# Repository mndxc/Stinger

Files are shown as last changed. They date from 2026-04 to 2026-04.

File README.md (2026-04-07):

# Stinger — USB Audio Soundboard
<p align="center">
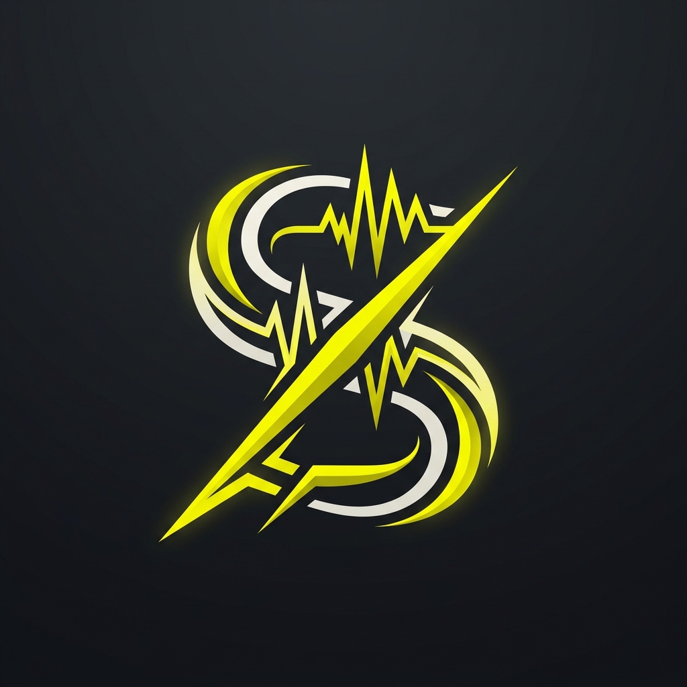
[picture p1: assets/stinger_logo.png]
Stinger Logo
  
</p>

<p align="center">
  <strong>High-performance, ultra-low latency audio workstation powered by ESP32-S3.</strong>
</p>

<p align="center">
  
  
  
  
</p>

---

**Stinger** is a professional-grade USB Audio Soundboard and interface designed for creators, streamers, and audio enthusiasts. Built on the **ESP32-S3** and the **ES8388 Audio Codec**, it combines a high-fidelity sound engine with a modular, tactile hardware interface.

## ✨ Key Features

- **🚀 Professional Audio Engine**: 16-bit / 48kHz PCM playback with sub-10ms trigger latency.
- **🎹 5×5 Matrix Input**: 25 tactile keys with integrated **1N4148 ghosting protection** for complex multi-key triggers.
- **📟 Sharp UI**: 2.9" E-Paper display (296x128) providing high-contrast bank indicators, labels, and real-time status.
- **🔊 Dual Rotary Encoders**: Dedicated physical controls for **System Bank Switching** and **SD Gain Leveling**.
- **💾 PSRAM Powered**: High-speed pre-loading of audio samples (up to 30s) into 8MB PSRAM for instantaneous playback.
- **🏗️ Modular Architecture**: Unique "Hinge" design with a specialized **Brain PCB** (SMT) and a hand-soldered **Plate PCB** (UI).
- **🔄 Auto-Sync Master Pin Map**: Smart build system that ensures hardware schematics and firmware constants are always in sync.

---

## 🏗️ Hardware Architecture: The "Long-Strap" Console

Stinger utilizes a modular **Two-Board Hinge** design to optimize signal integrity and mechanical stability.

- **Brain PCB (Base):** Optimized for signal integrity. Houses the ESP32-S3, high-fidelity ES8388 Codec, MicroSD slot, and power management.
- **Plate PCB (Interface):** Designed for manual assembly. Houses the 25-button MX-style matrix and the E-paper display.
- **Interconnect:** High-density 14-pin IDC ribbon headers connect the two layers, providing a robust electronic and mechanical bond.

> [!IMPORTANT]
> For full technical requirements, BOM, and assembly guides, see the [Hardware Specification](hardware/HARDWARE_SPEC.md).

---

## ⚙️ Firmware Stack: 3-Layer Architectural Model

Built on **ESP-IDF v6.0**, the firmware follows a strict 3-layer model to ensure long-term maintainability and performance:

1.  **Layer 1 (Drivers):** Low-level I2C/I2S/SPI drivers for the ES8388, E-Paper, and Matrix.
2.  **Layer 2 (Middleware):** High-level services for Audio Mixing (3-stream), SD management (with mutex protection), and USB UAC1/MSC stacks.
3.  **Layer 3 (Application):** The "Brain" of Stinger, coordinating state transitions, bank switching, and user event mapping.

> [!TIP]
> Check out the [Firmware Specification](firmware/stinger/FIRMWARE_SPEC.md) for task maps and concurrency details.

---

## 🚀 Getting Started

Ready to build your own Stinger? Follow these steps:

1.  **Clone the Repository:** `git clone https://github.com/mndxc/Stinger.git`
2.  **Environment Setup:** Follow the [GETTING_STARTED.md](GETTING_STARTED.md) guide.
3.  **Build & Flash:** 
    ```bash
    idf.py set-target esp32s3
    idf.py build
    idf.py flash monitor
    ```

---

## 📂 Repository Layout

```text
Stinger/
├── SPEC.md            # Master Project Overview & Master Pin Contract
├── hardware/          # KiCad design files, BOM, & Fabrications
├── firmware/          # ESP-IDF v6.0 source code & build tools
│   └── stinger/       # Main application logic
├── tools/             # Python utilities for pin-gen and audio prep
├── assets/            # Bitmap fonts, icons, and sample packs
└── build/             # Compiled artifacts (Git ignored)
```

---

## 📜 License

Distributed under the GNU General Public License v3.0. See `LICENSE` for more information.

**Project Lead:** [JP+](https://github.com/jonathanpool) | **Version:** 1.9 (Architectural Alignment)

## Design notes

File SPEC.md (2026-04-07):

# Stinger
## USB Audio Soundboard — Overview & Master Specification
**Revision 1.8 (Architectural Alignment) – Split Edition**
**Project:** Stinger | **Manufacturer:** JP+

> This document serves as the top-level project overview and the **Master Contract** between the Hardware and Firmware domains. For detailed subsystem specifications, refer to the linked documents below.

---

## 1. Project Specifications

The specification has been cleanly divided into hardware and firmware domains for ease of development:

- **[Hardware Specification](hardware/HARDWARE_SPEC.md)**: Schematics, layout guidelines, BOM, and protection circuitry.
- **[Firmware Specification](firmware/stinger/FIRMWARE_SPEC.md)**: RTOS tasks, display layouts, sound engine concurrency, and architecture guidelines.

---

## 2. Architecture: The "Long-Strap" Console

The Stinger uses a modular Two-Board Hinge design to optimize signal integrity and mechanical stability.

- **Brain PCB (Base):** Houses the ESP32-S3, ES8388 Codec, MicroSD slot, Power Section, and Rear I/O. Uses **Professional SMT** for fine-pitch ICs and **Manual THT** for IDC interconnects.
- **Plate PCB (Interface):** Houses the 25-button matrix and the 2.9" E-paper display. Fully **Hand-Soldered**.
- **Interconnect:** Two standard 14-pin IDC ribbon cables (2.54mm pitch) connect the boards via THT shrouded headers.

---

## 3. Master Pin Mapping & Matrix (The Contract)

**Note on Single Source of Truth:** This section is the *absolute contract* between the hardware design and the firmware implementation. Neither domain dictates the pins independently. 
- **Hardware:** Routes the schematics matching this table.
- **Firmware:** Reads from this table to define `firmware/main/pin_map.h`, which is the *code's* source of truth.

### 3.1 Pin Alignment Automation
To prevent "split-brain" discrepancies between PCB schematics and firmware constants, this project employs a centralized code generation strategy.
- **Source of Truth:** The pins are exclusively defined in `firmware/stinger/master_pins.json`.
- **Developer Workflow:** Setting your IDE workspace to `firmware/stinger/` is fully supported and recommended. You edit the JSON file directly. 
- **Under the Hood:** During CMake generation (`idf.py build` or `ninja`), a Python script (`tools/generate_pins.py`) is automatically executed. It builds `pin_map.h` for the firmware compiler and dynamically updates the Markdown table below. The script resolves paths natively relative to itself, meaning you can trigger builds and code-generation from any valid workspace context or terminal folder without filepath errors.

### 3.2 Pin Assignment Table (Rev V37)

<!-- PINS_START -->
<!-- The table below is auto-generated from firmware/stinger/master_pins.yaml during build. Do not edit. -->
| Pin Name | GPIO | Description/Note |
|---|---|---|
| `PIN_USB_D_MINUS` | GPIO 19 | USB D- |
| `PIN_USB_D_PLUS` | GPIO 20 | USB D+ |
| `PIN_I2S_BCLK` | GPIO 38 | I2S BCLK (Audio Data) |
| `PIN_I2S_LRCK` | GPIO 39 | I2S LRCK (Audio Data) |
| `PIN_I2S_DOUT` | GPIO 40 | I2S DOUT (Audio Data) |
| `PIN_I2S_DIN` | GPIO 41 | I2S DIN (Audio Data) |
| `PIN_I2S_MCLK` | GPIO 0 | I2S MCLK (CLK_OUT1. 256xFs = 12.288 MHz) |
| `PIN_I2C_SDA` | GPIO 4 | I2C SDA (Control) |
| `PIN_I2C_SCL` | GPIO 5 | I2C SCL (Control) |
| `PIN_SPI2_CS` | GPIO 10 | SPI2 CS (MicroSD) |
| `PIN_SPI2_MOSI` | GPIO 11 | SPI2 MOSI (MicroSD) |
| `PIN_SPI2_SCK` | GPIO 12 | SPI2 SCK (MicroSD) |
| `PIN_SPI2_MISO` | GPIO 13 | SPI2 MISO (MicroSD) |
| `PIN_SPI3_CS` | GPIO 21 | SPI3 CS (E-Paper) on non-strapping pin |
| `PIN_SPI3_DIN` | GPIO 16 | SPI3 DIN (E-Paper) |
| `PIN_SPI3_CLK` | GPIO 17 | SPI3 CLK (E-Paper) |
| `PIN_SPI3_DC` | GPIO 18 | SPI3 DC (E-Paper) |
| `PIN_SPI3_RST` | GPIO 7 | SPI3 RST (E-Paper) |
| `PIN_SPI3_BUSY` | GPIO 6 | SPI3 BUSY (E-Paper) |
| `PIN_MATRIX_ROW_0` | GPIO 1 | Matrix Row 0 |
| `PIN_MATRIX_ROW_1` | GPIO 2 | Matrix Row 1 |
| `PIN_MATRIX_ROW_2` | GPIO 42 | Matrix Row 2 |
| `PIN_MATRIX_ROW_3` | GPIO 43 | Matrix Row 3 |
| `PIN_MATRIX_ROW_4` | GPIO 25 | Matrix Row 4 |
| `PIN_MATRIX_COL_0` | GPIO 8 | Matrix Col 0 |
| `PIN_MATRIX_COL_1` | GPIO 15 | Matrix Col 1 (moved from GPIO 3 strapping pin) |
| `PIN_MATRIX_COL_2` | GPIO 44 | Matrix Col 2 |
| `PIN_MATRIX_COL_3` | GPIO 9 | Matrix Col 3 |
| `PIN_MATRIX_COL_4` | GPIO 24 | Matrix Col 4 |
| `PIN_ENC1_A` | GPIO 47 | Encoder 1 A (Bank switching) |
| `PIN_ENC1_B` | GPIO 14 | Encoder 1 B (Bank switching) |
| `PIN_ENC2_A` | GPIO 22 | Encoder 2 A (SD Gain) |
| `PIN_ENC2_B` | GPIO 23 | Encoder 2 B (SD Gain) |
| `PIN_SD_DETECT` | GPIO 26 | SD Card Detect (Active low) |
| `PIN_STATUS_LED` | GPIO 48 | Status RGB LED |
<!-- PINS_END -->

### 3.2 Logical Matrix Map (5×5)

| Row \ Col | Col 0 (GPIO 8) | Col 1 (GPIO 15) | Col 2 (GPIO 44) | Col 3 (GPIO 9) | Col 4 (GPIO 24) |
|---|---|---|---|---|---|
| Row 0 (GPIO 1)  | Trigger L1 | Trigger L2 | Trigger L3 | Trigger L4 | Reserved |
| Row 1 (GPIO 2)  | Trigger R1 | Trigger R2 | Trigger R3 | Trigger R4 | Reserved |
| Row 2 (GPIO 42) | Fav 1 | Fav 2 | Fav 3 | Fav 4 | Reserved |
| Row 3 (GPIO 43) | Fav 5 | Shift Key | Enc 1 Switch | Enc 2 Switch | Reserved |
| Row 4 (GPIO 25) | Reserved | Reserved | Reserved | Reserved | Reserved |

---

## 4. Repository Layout

```
stinger/
│
├── SPEC.md                        # This document (Project Overview & Master Pin Contract)
├── hardware/
│   ├── HARDWARE_SPEC.md           # Master hardware requirements
│   ├── brain/ ...
│   ├── plate/ ...
│   └── fabrication/ ...
│
├── firmware/
│   ├── stinger/
│   │   ├── master_pins.json       # Source of Truth for Pins
│   │   ├── FIRMWARE_SPEC.md       # Master firmware requirements
│   │   ├── main/
│   │   │   ├── pin_map.h          # Auto-generated code implementation
│   │   │   ├── board_config.h
│   │   │   └── stinger_app.c
│   │   ├── components/ ...
│   │   └── tools/
│   │       └── generate_pins.py   # Generator script
└── assets/ ...
```

---

## Revision History

| Revision | Summary of Changes |
|---|---|
| 1.0 | Initial consolidated release. |
| 1.1 | GPIO 15 → 21 for SPI3 CS. Matrix map added. FreeRTOS task map added. |
| 1.2 | Encoder phases moved off matrix to dedicated interrupt GPIOs. Priority order corrected. PSRAM loading strategy defined. SD mutex and Transfer Mode state machine specified. |
| 1.3 | GPIO 15 → 22 and GPIO 46 → 23 for Encoder 2 A/B (strapping-pin conflicts). Maximum sample length added. Transfer Mode VBUS exit clarified. Citation artifact removed. |
| 1.4 | Sample format changed to mono. Mixer routing clarified. Sample completion behavior defined. Max sample length extended to 30s. Variable PSRAM allocation. |
| 1.5 | Codec replaced: WM8960 (EOL) → ES8388 (C365736). MCLK added to pin map. Encoder 1 assigned to bank switching. Display specification added. Label file format defined. 99-bank system defined. Project directory added. ESP-IDF v5.3 target defined. |
| 1.6 | Full protection circuitry restored. SD card-detect added (GPIO 26). BOM rationalised. |
| 1.7 | Project renamed to **Stinger** by JP+. USB descriptor strings defined. Boot splash screen specified. |
| 1.8 | Formalized 3-Layer Architectural model. Document split into Hardware/Firmware specs, leaving Master Pin Contract in root `SPEC.md`. |
| 1.9 | Updated framework requirement to ESP-IDF v6.0 to align with current IDE extension defaults. |

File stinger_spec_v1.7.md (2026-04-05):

# Stinger
## USB Audio Soundboard — Comprehensive Design & Manufacturing Specification
**Revision 1.7 (V37 Consolidated)**
**Project:** Stinger | **Manufacturer:** JP+

> This document serves as the production-ready specification and design guide for the Stinger USB Audio Soundboard by JP+. This revision applies the project name throughout, defines USB device descriptor strings, and adds the boot splash screen specification.

---

# PART I: MASTER SYSTEM SPECIFICATION

---

## 1. Architecture: The "Long-Strap" Console

The Stinger uses a modular Two-Board Hinge design to optimize signal integrity and mechanical stability.

- **Brain PCB (Base):** Houses the ESP32-S3, ES8388 Codec, MicroSD slot, Power Section, and Rear I/O.
- **Plate PCB (Interface):** Houses the 16-button matrix and the 2.9" E-paper display.
- **Interconnect:** Two standard 10-pin IDC ribbon cables (2.54mm pitch) connect the boards.

---

## 2. Hardware Specification

### 2.1 MCU Module

- **Model:** ESP32-S3-WROOM-1-N8R8 (Octal SPI).
- **Forbidden Pins:** GPIO 33–37 (internal PSRAM/Flash).
- **Strapping:** GPIO 0 HIGH (10kΩ); GPIO 45 (VDD_SPI) LOW for 3.3V flash operation.

### 2.2 Audio Subsystem

- **Codec:** ES8388 (QFN-28, 4×4mm) by Everest Semiconductor. Actively manufactured.
- **Configuration:** 48kHz / 16-bit PCM, I2S slave mode.
- **I2C Address:** 0x10 (CE pin LOW) or 0x11 (CE pin HIGH). CE pin state must be defined in schematic and matched in `board_config.h`.
- **Output:** Board-mount 3.5mm TRRS jack (CTIA) on the front panel.
- **Power Pins:**

| ES8388 Supply Pin | Connected Rail | Notes |
|---|---|---|
| DVDD | 3.3V_D | Digital core supply. |
| AVDD | 3.3V_A | ADC/DAC analog supply. Isolated via ferrite bead + 10µF cap. |
| PVDD | 3.3V_D | PLL supply. Shares with DVDD. |
| HPVDD | 3.3V_D | Headphone amp supply. Decouple with 10µF + 100nF locally. |

### 2.3 TRRS Signal Path

| TRRS Pin (CTIA) | Signal | ES8388 Connection |
|---|---|---|
| Tip | Left Audio Out | LOUT1 via 1µF DC blocking cap, then PRTR5V0U2X TVS to GND |
| Ring 1 | Right Audio Out | ROUT1 via 1µF DC blocking cap, then PRTR5V0U2X TVS to GND |
| Ring 2 | Microphone In | LIN1 via 2.2kΩ bias resistor from MICBIAS, then PRTR5V0U2X TVS to GND |
| Sleeve | Ground | AGND |

> **TVS placement:** PRTR5V0U2X devices placed between TRRS jack pins and DC blocking caps / bias resistors. One package covers two channels — use two packages for all three active lines. Fourth channel is spare.

---

## 3. Protection & Glue Circuitry

### 3.1 USB Protection

- **VBUS PTC Fuse:** MF-MSMF050-2 (500mA hold, 1A trip, 1812) in series with VBUS before any other circuitry.
- **USB ESD:** USBLC6-2SC6 (SOT-23-6) placed immediately after USB-C connector pins, before PTC fuse. Rated 8kV contact discharge per IEC 61000-4-2.

### 3.2 TRRS Protection

- **TVS:** PRTR5V0U2X,215 (SOT-143, dual-channel). Two packages. Placed between jack pins and signal conditioning.

### 3.3 Matrix & Encoder Protection

- **Series Resistors:** 100Ω (0402) on every matrix Row and Column GPIO line (8 lines total).
- **Encoder Phase Lines:** 100Ω series resistors on all four encoder phase GPIOs (47, 14, 22, 23).

### 3.4 Programming & Reset Logic

- **Auto-Reset Circuit:** Dual NPN transistors (S8050) on RTS/DTR for automatic bootloader entry.
- **EN (Reset) Pin:** 10kΩ pull-up to 3.3V + 100nF cap to GND.
- **Boot Pin (GPIO 0):** 10kΩ pull-up to 3.3V + tactile button for manual Download Mode.
- **EN Button:** Tactile button for manual hardware reset.

### 3.5 Power & Status

- **Power Indicator:** Red LED on 3.3V rail via 1kΩ resistor.
- **Activity Indicator:** RGB LED on GPIO 48.
- **Ferrite Bead:** BLM18 series 0402 between 3.3V_D and 3.3V_A. 10µF + 100nF decoupling on 3.3V_A.

### 3.6 SD Card Detect

- MicroSD slot card-detect switch pin wired to GPIO 26.
- Firmware monitors via interrupt. Falling edge (removal) triggers clean unmount. Rising edge (insertion) triggers re-mount and Bank 01 reload.

---

## 4. Master Pin Mapping & Matrix

### 4.1 Pin Assignment Table (Rev V37)

| Bus / Function | Pin Assignment | Note |
|---|---|---|
| USB D− / D+ | GPIO 19 / 20 | |
| I2S (Audio Data)  | BCLK: 38, LRCK: 39, DOUT: 40, DIN: 41 | |
| I2S MCLK | GPIO 0 | CLK_OUT1. 256×Fs = 12.288 MHz. Enable after codec I2C init.  |
| I2C (Control) | SDA: 4, SCL: 5 | |
| SPI2 (MicroSD) | CS: 10, MOSI: 11, SCK: 12, MISO: 13 | |
| SPI3 (E-Paper) | CS: 21, DIN: 16, CLK: 17, DC: 18, RST: 7, BUSY: 6  | CS on non-strapping pin. |
| Matrix Rows | GPIO 1, 2, 42, 43 | Rows 0–3. 100Ω series on all row lines. |
| Matrix Cols | GPIO 8, 3, 44, 9 | Cols 0–3. 100Ω series on all col lines. |
| Encoder 1 A/B | GPIO 47, 14 | Dedicated interrupts. Bank switching. 100Ω series. |
| Encoder 2 A/B | GPIO 22, 23 | Dedicated interrupts. SD Gain. 100Ω series. |
| SD Card Detect | GPIO 26 | Active low. Card-detect switch on MicroSD slot. |
| Status RGB LED | GPIO 48 | |

### 4.2 Logical Matrix Map (4×4)

| Row \ Col | Col 0 (GPIO 8) | Col 1 (GPIO 3) | Col 2 (GPIO 44) | Col 3 (GPIO 9) |
|---|---|---|---|---|
| Row 0 (GPIO 1)  | Trigger L1 | Trigger L2 | Trigger L3 | Trigger L4 |
| Row 1 (GPIO 2)  | Trigger R1 | Trigger R2 | Trigger R3 | Trigger R4 |
| Row 2 (GPIO 42) | Fav 1 | Fav 2 | Fav 3 | Fav 4 |
| Row 3 (GPIO 43) | Fav 5 | Shift Key | Enc 1 Switch | Enc 2 Switch |

---

## 5. Display Specification

### 5.1 Hardware

- **Module:** Waveshare 2.9" E-paper, 296×128 pixels, portrait orientation (296px tall, 128px wide).
- **Interface:** SPI3 (dedicated bus).

### 5.2 Boot Splash Screen

On power-up, before Bank 01 is loaded, the Stinger displays a full-screen splash for 2 seconds:

```
┌────────────────────────────────┐
│                                │
│                                │
│                                │
│           STINGER              │  ← Large bold centered text (~48px tall)
│                                │
│             JP+                │  ← Smaller centered text (~20px tall)
│                                │
│                                │
│                                │
└────────────────────────────────┘
```

- **STINGER:** Large bold font, centered horizontally and vertically in the upper two-thirds of the display.
- **JP+:** Smaller font, centered beneath, with adequate spacing from STINGER.
- The splash uses the same full E-paper init refresh that occurs at power-on, so no additional refresh cycle is incurred.
- After 2 seconds, transition to the main Bank view (Zone layout, Section 5.3).
- If SD card is absent at boot, splash displays normally, then transitions to `NO SD CARD` state.

### 5.3 Main Screen Layout

```
┌────────────────────────────────┐  ← 0px
│         BANK INDICATOR         │  Zone 1: ~24px
├────────────────────────────────┤  ← 24px
│ ◄ L1  [     label text     ]   │
│ ◄ L2  [     label text     ]   │  Zone 2: 8 rows
│ ◄ L3  [     label text     ]   │  ~26px each = ~208px
│ ◄ L4  [     label text     ]   │
│    [ label text     ]  R1 ►    │
│    [ label text     ]  R2 ►    │
│    [ label text     ]  R3 ►    │
│    [ label text     ]  R4 ►    │
├────────────────────────────────┤  ← 232px
│  VOL: ██████░░  GAIN: ████░░░  │  Zone 3: ~32px
│  USB ●  SD ●  XFER ○           │
└────────────────────────────────┘  ← 296px
        ←── 128px wide ───→
```

**Zone 1 — Bank Indicator (~24px):**
- Centered bold: `Bank 03 / 99`
- Thin horizontal rule below.

**Zone 2 — Button Label Rows (~208px, ~26px per row):**
- Rows 1–4: Left buttons (L1–L4). `◄` at left edge, label left-aligned.
- Rows 5–8: Right buttons (R1–R4). Label right-aligned, `►` at right edge.
- Labels from `labels.cfg` if present, otherwise WAV filename without extension.
- Long labels truncated with ellipsis to fit 110px.
- Missing WAV slot displays `---`, key silenced.

**Zone 3 — Status Bar (~32px):**
- Row 1: Bar indicators for System Volume and SD Gain.
- Row 2: USB `●`, SD `●`, Transfer Mode `●` indicators.
- Lowest rendering priority — omitted cleanly if layout requires.

### 5.4 Bank Switching

- **Control:** Encoder 1. CW = next bank, CCW = previous bank. Wraps at boundaries.
- **At bank switch:** Full E-paper refresh. Active playback not interrupted.
- **Boot default:** Bank 01. Displays `NO BANK LOADED` if `/bank01/` absent.
- **On SD removal:** Displays `NO SD CARD`.
- **On SD insertion:** Reloads Bank 01 and refreshes display.

### 5.5 Label Files

```
# /bank01/labels.cfg
L1=Airhorn
L2=Rimshot
L3=Applause
L4=Sad Trombone
R1=Cash Register
R2=Crickets
R3=Wilhelm
R4=Ba Dum Tss
```

---

## 6. Firmware & Concurrency

### 6.1 Development Environment

- **Framework:** ESP-IDF v5.3 standalone.
- **ES8388 Driver:** Adapted from ESP-ADF `components/audio_hal/driver/es8388/`. Local component — no ESP-ADF pipeline dependency.
- **USB Stack:** TinyUSB (bundled with ESP-IDF v5.x). Composite device via `tusb_config.h`.
- **Target:** `esp32s3`. Dual-core task pinning via `xTaskCreatePinnedToCore`.

### 6.2 USB Device Descriptor Strings

| Descriptor Field | Value | Notes |
|---|---|---|
| Manufacturer | `JP+` | Appears in host OS device manager. |
| Product | `Stinger` | Appears as audio device and MSC drive name. |
| Serial Number | TBD | Can use ESP32-S3 unique MAC-derived ID at runtime. |
| UAC1 Interface | `Stinger Audio` | Audio device name shown in host audio settings. |
| MSC Volume Label | `STINGER` | Drive label shown in host file manager during Transfer Mode. |

### 6.3 FreeRTOS Task Map

| Core | Task Name | Priority | Responsibility |
|---|---|---|---|
| Core 1 | AudioMixerTask | 25 (Max) | SD data fetch, 3-stream mixing, I2S DMA. |
| Core 0 | UsbStackTask | 22 | UAC1, HID, and MSC events. |
| Core 0 | InputScanTask  | 20 | 4×4 matrix scan (1ms). Encoder rotation via interrupts. |
| Core 1 | SdManagerTask  | 15 | File handles, MSC data piping, card-detect handler. |
| Core 0 | DisplayTask | 2 | E-paper SPI refreshes. |

### 6.4 Playback Logic

- **Mode:** Retrigger — new key press restarts sample from beginning.
- **Sample Format:** 16-bit PCM, 48kHz Mono WAV.
- **Routing:** Samples sum into mono mic capture path → UAC1 capture stream to host.
- **Stream Summary:**
  - **UAC1 Capture (to PC):** Mono mic + mono SD sample (summed).
  - **UAC1 Playback (from PC):** Stereo USB audio → headphone output.
  - **Headphone Output:** Stereo USB playback + sidetone.
- **Sample Completion:** Sample channel zeroed on buffer exhaustion. Clean return to mic-only.

### 6.5 Encoder Logic

| Encoder | Function | Notes |
|---|---|---|
| Encoder 1 | Bank Switching | CW = next bank, CCW = previous bank. Wraps. |
| Encoder 2 | SD Gain | Internal mixer scaling. No HID event emitted. |

### 6.6 Sample File Specification

- **Format:** 16-bit PCM, 48kHz Mono WAV.
- **Typical Length:** Under 6 seconds (~576 KB).
- **Maximum Length:** 30 seconds hard cap (~2.88 MB). Boot loader rejects oversized files, logs via USB CDC.
- **Loading Strategy:** Pre-loaded into PSRAM at boot or bank-switch. Per-file allocation.
- **Naming:** `/bankXX/YY.wav` — XX = zero-padded bank (01–99), YY = button index (01–08).
- **Button index mapping:** 01–04 = L1–L4, 05–08 = R1–R4.

> **PSRAM budget:** 8 × 2.88 MB theoretical max ≈ 23 MB. Hard cap enforced at load time. Typical usage well under 5 MB.

### 6.7 Concurrency & Transfer Mode

#### SD Mutex Strategy
All SD access gated by `sd_card_mutex`. No task reads or writes SD without holding this mutex.

#### SD Card-Detect Handler
On removal (GPIO 26 falling edge): `AudioMixerTask` drains and suspends, mutex released, filesystem unmounted. Display shows `NO SD CARD`. On insertion: filesystem re-mounted, Bank 01 loaded, `AudioMixerTask` resumed.

#### Transfer Mode State Machine
- **Entry:** 2-second Shift + Enc2 Switch hold. `AudioMixerTask` drains DMA buffer, suspends via `vTaskSuspend()`. Mutex released, filesystem unmounted, SD handed to USB MSC. Display shows `TRANSFER MODE`. MSC drive appears as `STINGER` on host.
- **Exit — Combo:** Same Shift + Enc2 Switch hold. Filesystem re-mounted, `AudioMixerTask` resumed.
- **Exit — USB Disconnect:** VBUS loss triggers same re-mount and resume. Do not rely on host enumeration signals.

#### Known Limitation — FAT32 Power Loss
FAT32 is not journaled. Power loss during Transfer Mode SD writes may cause filesystem corruption. Acceptable for prototype. Production mitigation: ESP-IDF FatFS wear-leveling layer.

---

# PART II: KICAD HARDWARE DESIGN

---

## 7. Board Layout Strategy

- **Zone A (Rear):** USB-C connector, USBLC6-2SC6, PTC fuse, Power Switch, LDO.
- **Zone B (Center):** ESP32-S3, IDC headers for ribbon cables.
- **Zone C (Front):** ES8388 Codec, TRRS jack, PRTR5V0U2X TVS devices.

> **ESD placement rule:** USBLC6-2SC6 within 5mm of USB-C pins, before PTC fuse. PRTR5V0U2X between TRRS jack pads and first passive on each signal line.

## 8. Signal Integrity & Safety

- **Analog Ground Island:** ES8388 AVDD and AGND on isolated copper island. Star-ground via 0Ω resistor near LDO.
- **Encoder Interrupts:** Dedicated GPIOs with 100Ω series resistors. Not matrix-scanned.
- **Ribbon Isolation:** SHIFT_KEY (Header B, Pin 9) kept distant from SPI_CLK (Header B, Pin 4).
- **Boot Window:** GPIO 1 and GPIO 3 tri-stated during power-on strapping window.
- **MCLK Boot Safety:** GPIO 0 MCLK output enabled only after ES8388 I2C init completes.
- **Debug:** All logs via USB CDC. UART0 unavailable in production.

---

## 9. Bill of Materials (Consolidated)

### 9.1 Primary ICs

| Component | Part | LCSC | Notes |
|---|---|---|---|
| MCU Module | ESP32-S3-WROOM-1-N8R8 | C2913148 | |
| Audio Codec | ES8388 | C365736 | QFN-28, 4×4mm |
| LDO Regulator | SGM2019-3.3 | C16193 | 3.3V, 300mA |

### 9.2 Protection

| Component | Part | LCSC | Notes |
|---|---|---|---|
| USB ESD | USBLC6-2SC6 | C7519 | SOT-23-6. ST. Within 5mm of USB-C pins. |
| TRRS TVS | PRTR5V0U2X,215 | C12333 | SOT-143, dual-channel. Nexperia. Qty: 2. |
| VBUS PTC Fuse | MF-MSMF050-2 | C17313 | 500mA hold / 1A trip. 1812. |

### 9.3 Passives (Consolidated)

| Value | Package | Role |
|---|---|---|
| 100nF | 0402 | Bypass / decoupling on all IC supply pins. |
| 1µF | 0402 | DC blocking on TRRS audio lines. |
| 10µF | 0805 | Bulk decoupling: 3.3V_A, HPVDD, LDO output. |
| 100Ω | 0402 | Series ESD protection: matrix rows, cols, encoder phases. |
| 1kΩ | 0402 | Power LED current limit. |
| 2.2kΩ | 0402 | MICBIAS to TRRS Ring 2. |
| 4.7kΩ | 0402 | I2C SDA/SCL pull-ups. |
| 10kΩ | 0402 | GPIO pull-ups: EN, Boot, strapping. |

### 9.4 Miscellaneous

| Component | Notes |
|---|---|
| USB-C Connector | Mid-mount or right-angle top-mount (e.g. LCSC C165948). |
| MicroSD Slot | Must include card-detect switch pin. Wire CD to GPIO 26. |
| TRRS Jack | PJ-320A or equivalent. 3.5mm board-mount. CTIA. |
| Tactile Buttons ×2 | EN reset + Boot mode. Standard 6×6mm. |
| Ferrite Bead | BLM18 series 0402. 3.3V_D → 3.3V_A isolation. |
| NPN Transistors ×2 | S8050. Auto-reset RTS/DTR circuit. |
| Red LED | Power indicator on 3.3V rail. |
| RGB LED | Activity/status on GPIO 48. |

---

# PART III: PROJECT STRUCTURE

---

## 10. Repository Layout

```
stinger/
│
├── SPEC.md                        # This document (canonical project reference)
├── README.md                      # Project overview and build instructions
├── .gitignore
│
├── hardware/
│   ├── brain/
│   │   ├── brain.kicad_pro
│   │   ├── brain.kicad_sch
│   │   ├── brain.kicad_pcb
│   │   └── brain_bom.csv
│   ├── plate/
│   │   ├── plate.kicad_pro
│   │   ├── plate.kicad_sch
│   │   └── plate.kicad_pcb
│   ├── symbols/
│   │   └── ES8388.kicad_sym
│   ├── footprints/
│   │   └── ES8388_QFN28.kicad_mod
│   └── fabrication/
│       ├── brain/
│       └── plate/
│
├── firmware/
│   ├── CMakeLists.txt
│   ├── sdkconfig
│   ├── sdkconfig.defaults
│   │
│   ├── main/
│   │   ├── CMakeLists.txt
│   │   ├── main.c
│   │   ├── pin_map.h              # Single source of truth for all GPIO assignments
│   │   └── board_config.h         # Constants: sample rate, bank count, I2C address, etc.
│   │
│   └── components/
│       ├── es8388/                # ES8388 driver (adapted from ESP-ADF, no ADF dependency)
│       │   ├── CMakeLists.txt
│       │   ├── es8388.c
│       │   └── es8388.h
│       ├── audio_mixer/
│       │   ├── CMakeLists.txt
│       │   ├── audio_mixer.c
│       │   └── audio_mixer.h
│       ├── usb_audio/             # TinyUSB composite: UAC1 + HID + MSC
│       │   ├── CMakeLists.txt
│       │   ├── usb_descriptors.c  # Descriptor tables. Strings: "JP+", "Stinger".
│       │   ├── usb_audio.c
│       │   └── usb_audio.h
│       ├── sd_manager/            # SD mount, file loading, card-detect, mutex
│       │   ├── CMakeLists.txt
│       │   ├── sd_manager.c
│       │   └── sd_manager.h
│       ├── input_handler/         # Matrix scan, encoder ISRs, bank switching
│       │   ├── CMakeLists.txt
│       │   ├── input_handler.c
│       │   └── input_handler.h
│       └── display/               # E-paper driver + zone renderer + boot splash
│           ├── CMakeLists.txt
│           ├── display.c          # SPI driver, Waveshare 2.9" init, splash sequence
│           ├── display.h
│           ├── layout.c           # Zone rendering: splash, bank view, error states
│           └── layout.h
│
├── tools/
│   ├── flash.sh                   # Wrapper for idf.py flash monitor
│   └── wav_prep.py                # Validates WAV files to spec before SD copy
│
└── assets/
    ├── fonts/                     # Bitmap fonts for E-paper rendering
    └── sample_banks/
        └── bank01/
            ├── 01.wav
            └── labels.cfg
```

### 10.1 Key File Conventions

- **`pin_map.h`** — single source of truth for all GPIO numbers. No magic numbers elsewhere.
- **`board_config.h`** — all non-GPIO constants: sample rate (48000), bit depth (16), max banks (99), max sample frames, ES8388 I2C address, MCLK frequency (12288000), USB strings (`"JP+"`, `"Stinger"`), splash duration (2000ms).
- **`sdkconfig`** — committed to repo. All developers and AI tools build against identical ESP-IDF config.
- **`wav_prep.py`** — validates WAV files for spec compliance (48kHz, 16-bit, mono) and checks duration against 30-second cap before SD copy.

---

## Revision History

| Revision | Summary of Changes |
|---|---|
| 1.0 | Initial consolidated release. |
| 1.1 | GPIO 15 → 21 for SPI3 CS. Matrix map added. FreeRTOS task map added. |
| 1.2 | Encoder phases moved off matrix to dedicated interrupt GPIOs. Priority order corrected. PSRAM loading strategy defined. SD mutex and Transfer Mode state machine specified. |
| 1.3 | GPIO 15 → 22 and GPIO 46 → 23 for Encoder 2 A/B (strapping-pin conflicts). Maximum sample length added. Transfer Mode VBUS exit clarified. Citation artifact removed. |
| 1.4 | Sample format changed to mono. Mixer routing clarified. Sample completion behavior defined. Max sample length extended to 30s. Variable PSRAM allocation. |
| 1.5 | Codec replaced: WM8960 (EOL) → ES8388 (C365736). MCLK added to pin map. Encoder 1 assigned to bank switching. Display specification added. Label file format defined. 99-bank system defined. Project directory added. ESP-IDF v5.3 target defined. |
| 1.6 | Full protection circuitry restored: VBUS PTC fuse (C17313), USB ESD (C7519), TRRS TVS (C12333 ×2), matrix 100Ω series resistors. SD card-detect added (GPIO 26). BOM rationalised to 8 passive values. FAT32 power-loss limitation documented. |
| 1.7 | Project renamed to **Stinger** by JP+. Name applied throughout all sections and directory structure. USB descriptor strings defined: Manufacturer `JP+`, Product `Stinger`, UAC1 `Stinger Audio`, MSC volume `STINGER`. Serial number deferred to runtime MAC-derived ID. Boot splash screen specified (2s, STINGER / JP+ centered). USB strings added to `board_config.h` conventions. |

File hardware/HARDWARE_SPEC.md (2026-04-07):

# Stinger: Hardware Specification
**Revision 1.9 — Hybrid Assembly Model**

> [!IMPORTANT]
> **Navigation & Source of Truth**  
> *   **Pin Mapping:** Refer to the root [SPEC.md](file:///Users/jonathanpool/Projects/Stinger/SPEC.md) (Source of Truth).
> *   **Detailed Design Notes:** Refer to [KICAD_DESIGN_NOTES.md](file:///Users/jonathanpool/Projects/Stinger/hardware/KICAD_DESIGN_NOTES.md) for layout rules.
> *   **BOM & Sourcing:** The table in **Section 5** of *this document* is the absolute Source of Truth for parts.

---

## 1. Assembly Strategy

The Stinger uses a **Hybrid Assembly Model** to balance complexity and ease of construction:

| Board | Assembly Method | Description |
|---|---|---|
| **Brain PCB** | **Mixed Mode** | **Professional SMT** for fine-pitch ICs/passives. **Manual THT** for IDC headers. |
| **Plate PCB** | **Hand-Soldered** | Contains buttons, diodes, and through-hole headers. Uses larger pads (0805 or THT) for manual assembly. |

---

## 2. Hardware Specification

### 2.1 MCU Module
- **Model:** ESP32-S3-WROOM-1-N8R8.
- **Strapping:** GPIO 0 HIGH (10kΩ); GPIO 45 LOW (10kΩ).

### 2.2 Audio Subsystem
- **Codec:** ES8388 (QFN-28). 48kHz / 16-bit PCM.
- **I2C Address:** 0x10 (CE pin LOW).

### 2.3 TRRS signal Path
- **Protection:** PRTR5V0U2X TVS devices on all active lines. 1µF DC-blocking caps on L/R outputs.

### 2.4 Matrix & Input Protection
- **Series Resistors:** **100Ω (0402)** on all matrix lines and encoder phases. **Located on Brain PCB** for professional placement.
- **Ghosting Protection:** **25× 1N4148 diodes** (SOD-123 or THT). **Located on Plate PCB** at each switch node.
- **Orientation:** Cathode to Matrix Row (for active-low scan).

### 2.5 E-Paper Display Module
- **Model:** 2.9" E-Paper Module (e.g., Waveshare).
- **Interconnect:** **8-pin through-hole header (2.54mm)** on Plate PCB. Hand-wired to the display module.

### 2.6 SD Card & Power
- **SD Slot:** Includes card-detect switch on GPIO 26.
- **Auto-Reset:** Dual S8050 NPN circuit for RTS/DTR.

---

## 3. Board Layout Strategy

- **Brain (SMT Zone):** Concentrated fine-pitch routing for audio/USB. IDC headers are THT and should be soldered manually after SMT assembly to save on fixture fees.
- **Plate (Manual Zone):** Spacious layout for MX-style keys, 0805 resistors (if any), and easily accessible THT pads for the display module and IDC headers.

---

## 4. Maintenance & Change Management

To keep the hardware and software in sync, follow these rules for every change:
1.  **Pins:** Update `firmware/stinger/master_pins.json` first. Run `idf.py build` to propagate changes to `SPEC.md`.
2.  **BOM:** Update Section 5 of this document.
3.  **Footprints:** If switching from SMD to THT on the Plate, update the KiCad project and this spec simultaneously.

---

## 5. Bill of Materials (Master Source of Truth)

### 5.1 Brain PCB — Professional SMT Items (LCSC)

| Component | Part / Value | LCSC | Note |
|---|---|---|---|
| MCU | ESP32-S3-WROOM-1-N8R8 | C2913148 | |
| Audio Codec | ES8388 | C365736 | QFN-28 |
| LDO | SGM2019-3.3 | C16193 | 3.3V, 300mA |
| USB ESD | USBLC6-2SC6 | C7519 | Within 5mm of USB-C |
| TRRS TVS | PRTR5V0U2X,215 | C12333 | Qty: 2 |
| PTC Fuse | MF-MSMF050-2 | C17313 | 1812 package |
| USB-C | RA Top-Mount | C165948 | |
| MicroSD | With Card Detect | C91145 | |
| Series Resists | 100Ω (0402) | | Qty: 14 |
| Passives | 100nF, 1uF, 10uF | | Refer to KiCad Project |

### 5.2 Brain PCB — Hand-Soldered / User-Side Items
*These items are through-hole and should be installed manually to avoid JLCPCB's THT assembly and fixture surcharges.*

| Component | Part / Value | LCSC | Note |
|---|---|---|---|
| IDC Headers | 2×7 Box Header | C2922129 | 2.54mm THT. Placed on top side. |

### 5.3 Plate PCB — Hand-Soldered / Manual Items
*This entire board is intended for manual assembly.*

| Component | Part / Value | Sourcing | Note |
|---|---|---|---|
| Keys | MX-Style or Tactile | Generic | 25 required |
| Diodes | 1N4148W (SOD-123) | C1661 | or THT 1N4148 (C467) |
| IDC Headers | 2×7 Box Header | C2922129 | 2.54mm THT. Placed on bottom side. |
| E-Paper | 2.9" Module | Waveshare | With 8-pin breakout |
| Status LED | WS2812B (5050) | C114586 | 1 required |
| Ribbon Cable | 14-pin IDC Assembly | Generic | Qty: 2 |

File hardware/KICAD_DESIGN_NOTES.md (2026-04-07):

# Stinger — KiCad Design Notes
**Revision 2.0 — Hybrid Assembly Edition**

> [!IMPORTANT]
> **Navigation & Source of Truth**  
> *   **Pin Mapping:** Refer to the root [SPEC.md](file:///Users/jonathanpool/Projects/Stinger/SPEC.md) (Source of Truth).
> *   **Master BOM:** All part numbers and LCSC codes are in [HARDWARE_SPEC.md §5](file:///Users/jonathanpool/Projects/Stinger/hardware/HARDWARE_SPEC.md#L98).
> *   **Sync:** Update `master_pins.json` before changing any schematic nets.

---

## 1. Assembly & Sourcing Strategy

The Stinger is a **two-board design** optimized for a mix of professional and manual construction:

| Board | Directory | Assembly | Key Contents |
|---|---|---|---|
| **Brain PCB** | `hardware/brain/` | **Mixed Mode** | **Professional SMT** for fine-pitch ICs/passives. **Manual THT** for IDC headers. |
| **Plate PCB** | `hardware/plate/` | **Hand-Soldered** | Buttons, Ghosting Diodes, WS2812B, and IDC Headers. |

---

## 2. MCU Module — ESP32-S3-WROOM-1-N8R8

### 2.1 Strapping Pins — Critical at Power-On
These pins determine the boot mode. Ensure the Brain PCB includes these 10kΩ pull-up/down resistors for the SMT machine to place.

| GPIO | Required Level | Implementation |
|---|---|---|
| **GPIO 0** (Boot) | HIGH | 10kΩ pull-up. Tactile button to GND for Download Mode. |
| **GPIO 45** (VDD_SPI) | LOW | 10kΩ pull-down. Selects 3.3V internal flash. |

### 2.2 MCLK Boot Safety (GPIO 0)
- GPIO 0 outputs the 12.288 MHz MCLK to the ES8388.
- **Schematic Note:** Ensure MCLK is enabled in firmware *only* after ES8388 I2C initialization to avoid interference with the boot strapping window.

---

## 3. Complete Pin Assignment (Master Reference)

> **Auto-Updated From:** `firmware/stinger/master_pins.json`.

| Function | GPIO | Net Name | Location |
|---|---|---|---|
| I2S MCLK | 0 | `I2S_MCLK` | Brain |
| I2C SDA | 4 | `I2C_SDA` | Brain |
| I2C SCL | 5 | `I2C_SCL` | Brain |
| SD CS | 10 | `SD_CS` | Brain |
| Matrix Rows | 1, 2, 42, 43, 25 | `MTX_R[0:4]` | Crossing Interconnect |
| Matrix Cols | 8, 15, 44, 9, 24 | `MTX_C[0:4]` | Crossing Interconnect |
| EPD SPI | 21, 16, 17, 18, 7, 6 | `EPD_*` | Crossing Interconnect |
| RGB LED | 48 | `STATUS_LED` | Crossing Interconnect |

---

## 4. Matrix & Display Implementation (Plate PCB)

### 4.1 5×5 Matrix Diodes
- **Ghosting Fix:** Place a **1N4148** diode at every switch node.
- **Orientation:** **Cathode to Row**. This allows the scanner (Rows as outputs, Columns as pull-up inputs) to operate correctly.
- **Footprint:** Use **SOD-123** for a compact hand-solder or **DO-35 (THT)** for a classic look.

### 4.2 E-Paper Display Module
- **Strategy:** Do not use a raw FPC connector.
- **Physical:** Use an **8-pin through-hole header (2.54mm)** on the Plate PCB.
- **Wiring:** Manually wire the Waveshare (or equivalent) E-paper module to these pads.
- **Pins:** VCC, GND, DIN, CLK, CS, DC, RST, BUSY.

---

## 5. Power & Supply Rails

- **LDO:** SGM2019-3.3 (Brain). Output `3.3V_D`.
- **Analog Island:** ES8388 `AVDD/AGND` isolated via ferrite bead and 10µF cap on the Brain.
- **Star-Ground:** Connect AGND to main GND at a single point near the LDO on the Brain.

---

## 6. Protection Circuitry Layout (Brain PCB)

- **USB ESD:** `USBLC6-2SC6` must be within **5mm** of USB-C pads.
- **TRRS TVS:** `PRTR5V0U2X` between jack pads and DC-blocking caps.
- **Series Resistors:** All **14 × 100Ω 0402** resistors should be placed near the ESP32-S3 pins on the Brain.

---

## 7. Board-to-Board Interconnect (IDC)

- **Headers:** Two **14-pin (2×7)** 2.54mm pitch shrouded headers.
- **Cable:** Standard 14-way flat ribbon.
- **Signal Integrity:** Use the 5 spare/GND pins on the headers to interleave ground between `EPD_CLK` and sensitive data lines like `SD_CS`.

---

## 8. Checklist Before Finalizing Design

- [ ] All 25 matrix buttons have a ghosting protection diode (Cathode to Row).
- [ ] Brain PCB contains all 0402 passives and fine-pitch ICs for SMT.
- [ ] IDC headers on Brain PCB are excluded from SMT pick-and-place to save on THT fees.
- [ ] Plate PCB pads for E-paper and IDC are through-hole for easy wiring.
- [ ] Pin map matches the root `SPEC.md` and `master_pins.json`.
- [ ] Analog ground island on Brain is isolated and star-grounded.

---

## 9. Sourcing Quick Links

> Refer to [HARDWARE_SPEC.md §5](file:///Users/jonathanpool/Projects/Stinger/hardware/HARDWARE_SPEC.md#L98) for exact LCSC parts and counts. Don't mirror the BOM here to prevent version drift.

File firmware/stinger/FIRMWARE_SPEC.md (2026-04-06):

# Stinger: Firmware Specification

> This document details the firmware architecture, concurrency model, and display rendering logic for the Stinger USB Audio Soundboard. For the master pin mapping, refer to the root `SPEC.md`.

## 1. Display Specification

### 1.1 Hardware

- **Module:** Waveshare 2.9" E-paper, 296×128 pixels, portrait orientation (296px tall, 128px wide).
- **Interface:** SPI3 (dedicated bus).

### 1.2 Boot Splash Screen

On power-up, before Bank 01 is loaded, the Stinger displays a full-screen splash for 2 seconds:

```
┌────────────────────────────────┐
│                                │
│                                │
│                                │
│           STINGER              │  ← Large bold centered text (~48px tall)
│                                │
│             JP+                │  ← Smaller centered text (~20px tall)
│                                │
│                                │
│                                │
└────────────────────────────────┘
```

- **STINGER:** Large bold font, centered horizontally and vertically in the upper two-thirds of the display.
- **JP+:** Smaller font, centered beneath, with adequate spacing from STINGER.
- The splash uses the same full E-paper init refresh that occurs at power-on, so no additional refresh cycle is incurred.
- After 2 seconds, transition to the main Bank view (Zone layout, Section 1.3).
- If SD card is absent at boot, splash displays normally, then transitions to `NO SD CARD` state.

### 1.3 Main Screen Layout

```
┌────────────────────────────────┐  ← 0px
│         BANK INDICATOR         │  Zone 1: ~24px
├────────────────────────────────┤  ← 24px
│ ◄ L1  [     label text     ]   │
│ ◄ L2  [     label text     ]   │  Zone 2: 8 rows
│ ◄ L3  [     label text     ]   │  ~26px each = ~208px
│ ◄ L4  [     label text     ]   │
│    [ label text     ]  R1 ►    │
│    [ label text     ]  R2 ►    │
│    [ label text     ]  R3 ►    │
│    [ label text     ]  R4 ►    │
├────────────────────────────────┤  ← 232px
│  VOL: ██████░░  GAIN: ████░░░  │  Zone 3: ~32px
│  USB ●  SD ●  XFER ○           │
└────────────────────────────────┘  ← 296px
        ←── 128px wide ───→
```

**Zone 1 — Bank Indicator (~24px):**
- Centered bold: `Bank 03 / 99`
- Thin horizontal rule below.

**Zone 2 — Button Label Rows (~208px, ~26px per row):**
- Rows 1–4: Left buttons (L1–L4). `◄` at left edge, label left-aligned.
- Rows 5–8: Right buttons (R1–R4). Label right-aligned, `►` at right edge.
- Labels from `labels.cfg` if present, otherwise WAV filename without extension.
- Long labels truncated with ellipsis to fit 110px.
- Missing WAV slot displays `---`, key silenced.

**Zone 3 — Status Bar (~32px):**
- Row 1: Bar indicators for System Volume and SD Gain.
- Row 2: USB `●`, SD `●`, Transfer Mode `●` indicators.
- Lowest rendering priority — omitted cleanly if layout requires.

### 1.4 Bank Switching

- **Control:** Encoder 1. CW = next bank, CCW = previous bank. Wraps at boundaries.
- **At bank switch:** Full E-paper refresh. Active playback not interrupted.
- **Boot default:** Bank 01. Displays `NO BANK LOADED` if `/bank01/` absent.
- **On SD removal:** Displays `NO SD CARD`.
- **On SD insertion:** Reloads Bank 01 and refreshes display.

### 1.5 Label Files

```
# /bank01/labels.cfg
L1=Airhorn
L2=Rimshot
L3=Applause
L4=Sad Trombone
R1=Cash Register
R2=Crickets
R3=Wilhelm
R4=Ba Dum Tss
```

---

## 2. Firmware & Concurrency

### 2.1 Development Environment

- **Framework:** ESP-IDF v6.0 standalone.
- **ES8388 Driver:** Adapted from ESP-ADF `components/audio_hal/driver/es8388/`. Local component — no ESP-ADF pipeline dependency.
- **USB Stack:** TinyUSB (bundled with ESP-IDF v5.x). Composite device via `tusb_config.h`.
- **Target:** `esp32s3`. Dual-core task pinning via `xTaskCreatePinnedToCore`.

### 2.2 USB Device Descriptor Strings

| Descriptor Field | Value | Notes |
|---|---|---|
| Manufacturer | `JP+` | Appears in host OS device manager. |
| Product | `Stinger` | Appears as audio device and MSC drive name. |
| Serial Number | TBD | Can use ESP32-S3 unique MAC-derived ID at runtime. |
| UAC1 Interface | `Stinger Audio` | Audio device name shown in host audio settings. |
| MSC Volume Label | `STINGER` | Drive label shown in host file manager during Transfer Mode. |

### 2.3 FreeRTOS Task Map

| Core | Task Name | Priority | Responsibility |
|---|---|---|---|
| Core 1 | AudioMixerTask | 25 (Max) | SD data fetch, 3-stream mixing, I2S DMA. |
| Core 0 | UsbStackTask | 22 | UAC1, HID, and MSC events. |
| Core 0 | InputScanTask  | 20 | 4×4 matrix scan (1ms). Encoder rotation via interrupts. |
| Core 1 | SdManagerTask  | 15 | File handles, MSC data piping, card-detect handler. |
| Core 0 | DisplayTask | 2 | E-paper SPI refreshes. |

### 2.4 Playback Logic

- **Mode:** Retrigger — new key press restarts sample from beginning.
- **Sample Format:** 16-bit PCM, 48kHz Mono WAV.
- **Routing:** Samples sum into mono mic capture path → UAC1 capture stream to host.
- **Stream Summary:**
  - **UAC1 Capture (to PC):** Mono mic + mono SD sample (summed).
  - **UAC1 Playback (from PC):** Stereo USB audio → headphone output.
  - **Headphone Output:** Stereo USB playback + sidetone.
- **Sample Completion:** Sample channel zeroed on buffer exhaustion. Clean return to mic-only.

### 2.5 Encoder Logic

| Encoder | Function | Notes |
|---|---|---|
| Encoder 1 | Bank Switching | CW = next bank, CCW = previous bank. Wraps. |
| Encoder 2 | SD Gain | Internal mixer scaling. No HID event emitted. |

### 2.6 Sample File Specification

- **Format:** 16-bit PCM, 48kHz Mono WAV.
- **Typical Length:** Under 6 seconds (~576 KB).
- **Maximum Length:** 30 seconds hard cap (~2.88 MB). Boot loader rejects oversized files, logs via USB CDC.
- **Loading Strategy:** Pre-loaded into PSRAM at boot or bank-switch. Per-file allocation.
- **Naming:** `/bankXX/YY.wav` — XX = zero-padded bank (01–99), YY = button index (01–08).
- **Button index mapping:** 01–04 = L1–L4, 05–08 = R1–R4.

> **PSRAM budget:** 8 × 2.88 MB theoretical max ≈ 23 MB. Hard cap enforced at load time. Typical usage well under 5 MB.

### 2.7 Concurrency & Transfer Mode

#### SD Mutex Strategy
All SD access gated by `sd_card_mutex`. No task reads or writes SD without holding this mutex.

#### SD Card-Detect Handler
On removal (GPIO 26 falling edge): `AudioMixerTask` drains and suspends, mutex released, filesystem unmounted. Display shows `NO SD CARD`. On insertion: filesystem re-mounted, Bank 01 loaded, `AudioMixerTask` resumed.

#### Transfer Mode State Machine
- **Entry:** 2-second Shift + Enc2 Switch hold. `AudioMixerTask` drains DMA buffer, suspends via `vTaskSuspend()`. Mutex released, filesystem unmounted, SD handed to USB MSC. Display shows `TRANSFER MODE`. MSC drive appears as `STINGER` on host.
- **Exit — Combo:** Same Shift + Enc2 Switch hold. Filesystem re-mounted, `AudioMixerTask` resumed.
- **Exit — USB Disconnect:** VBUS loss triggers same re-mount and resume. Do not rely on host enumeration signals.

#### Known Limitation — FAT32 Power Loss
FAT32 is not journaled. Power loss during Transfer Mode SD writes may cause filesystem corruption. Acceptable for prototype. Production mitigation: ESP-IDF FatFS wear-leveling layer.

---

## 3. Architectural Principles (Boilerplate vs. Application)

To ensure long-term maintainability and clear development flow, the Stinger firmware follows a strict **3-Layer Architectural Model**. All development (manual or AI-assisted) must adhere to these boundaries.

### 3.1 Layer 1: Hardware Abstraction & Drivers (Boilerplate)
**Location:** `firmware/components/{es8388, display, input_handler, ...}`
- **Responsibility:** Low-level register access, bus initialization (I2C/SPI/I2S), and GPIO management.
- **Constraint:** These modules must remain hardware-agnostic regarding the "Stinger" business logic. They provide the "tools" but do not know "why" they are being used.

### 3.2 Layer 2: Subsystem Services (Middleware)
**Location:** `firmware/components/{audio_mixer, sd_manager, usb_audio}`
- **Responsibility:** Managing complex stateful objects (audio buffers, file handles, USB descriptor tables).
- **Constraint:** These modules encapsulate FreeRTOS tasks and DMA complexity. They expose high-level APIs (e.g., `mixer_play_file()`) to the application layer.

### 3.3 Layer 3: Application Logic (The "Brain")
**Location:** `firmware/main/stinger_app.{h,c}`
- **Responsibility:** High-level soundboard behavior, state machine coordination, and user-interaction mapping.
- **Constraint:** This layer contains no low-level hardware code. It coordinates Layer 2 services to fulfill user requests (e.g., "If Key 1 is pressed in Bank 2 -> tell SD Manager to fetch file -> tell Mixer to play").

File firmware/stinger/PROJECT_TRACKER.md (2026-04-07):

# Stinger Firmware - AI Project Tracker

This document is the authoritative task-tracking resource for the Stinger USB Audio Soundboard firmware project. It serves as a continuous record of progress, breaking the project down from its current initialized state to the finished product as defined in `FIRMWARE_SPEC.md`.

## AI Instructions & Guidelines

When working on this project in an autonomous or pair-programming session, AI coding assistants must adhere to the following rules for managing this document:

### 1. Adding New Items
* Always add new tasks into the appropriate "Logical Phase" section.
* If a task is too large, break it down as nested bullet points under the main task.
* Format tasks consistently using standard markdown checklist syntax.

### 2. Status Indicators
Use the following strict indicators to denote the state of an item:
* `[ ]` **Unstarted**: Work has not begun.
* `[-]` **In Progress**: Work is currently underway or partially complete.
* `[x]` **Completed**: Implementation is complete, tested, and verified.
* `[!]` **Blocked**: Work cannot proceed until an external dependency or question is resolved.

### 3. Documenting Progress (Partially Complete Items)
* When updating an item to `[-]` (In Progress) or `[!]` (Blocked), you **must** add a sub-bullet starting with `> Update (YYYY-MM-DD):` directly below the task.
* Briefly detail what has been completed, what remains, or the exact nature of a blockage.
* *Example:*
  - [-] Implement SD Card read/write operations
    - > Update (2026-04-06): FAT32 mounting works, but DMA reading is currently throwing an underflow error. Debugging mixer priority.

### 4. Checking Off Items
* When a task is fully resolved, change its status to `[x]`. 
* You may leave the `> Update` progression history intact as an audit trail of how the task was solved, or summarise the final merged resolution.

---

## Current State Summary
* **Environment**: ESP-IDF v6.0 IDE configured.
* **Build System**: CMake configured. Project builds successfully.
* **Hardware Config**: Setup of `master_pins.yaml` and auto-generated `pin_map.h`.
* **Sub-module scaffolding**: `main.c` calls `stinger_app_init()`.

---

## Task Backlog (Logical Steps to Completion)

### Phase 0: Hardware Design Freeze (CRITICAL)
- [-] **Schematic & Pin Audit**: Review `master_pins.json` against ESP32-S3 strapping requirements.
  - > Update (2026-04-06): Hardware checklist created. Focus on GPIO 0 (MCLK) and GPIO 3 (Matrix) conflicts.
- [ ] **BOM Verification**: Confirm ES8388, E-paper, and SD card components meet electrical specs.
- [ ] **Circuit Protection**: Confirm anti-ghosting diodes and I2C pull-ups are in the layout.

### Phase 1: Hardware Abstraction & Drivers (Layer 1)
- [x] Initialize I2C Bus for Codec Communication
- [x] Integrate ES8388 Audio Codec Driver (Local Component)
  - > Update (2026-04-06): I2C Master initialized and ES8388 driver implemented. Verified via successful build and component registration.
- [ ] Initialize SPI3 Bus for Display Comm
- [ ] Integrate Waveshare 2.9" E-paper Display Driver
- [x] Initialize FreeRTOS `InputScanTask` (Core 0, Priority 20) for 4x4 Matrix
- [x] Integrate Rotary Encoders (Interrupt-driven updates)

### Phase 2: Core Subsystem Services (Layer 2)
- [ ] Initialize `SdManagerTask` (Core 1, Priority 15)
  - [ ] Implement FAT32 filesystem mounting via SPI/SDIO
  - [ ] Implement `sd_card_mutex` strategy
  - [ ] Implement Card-Detect GPIO callback (falling edge on GPIO 26)
- [ ] Initialize `UsbStackTask` (Core 0, Priority 22)
  - [ ] Setup TinyUSB descriptors (JP+, Stinger, etc.)
  - [ ] Implement UAC1 Audio interfaces (Capture & Playback)
  - [ ] Implement MSC interface for USB Mass Storage (Transfer Mode)
- [ ] Initialize `AudioMixerTask` (Core 1, Priority 25)
  - [ ] Setup I2S DMA for sending data to ES8388
  - [ ] Implement SD WAV file fetching (pre-load into PSRAM)
  - [ ] Implement 3-stream mono mixing logic 
  - [ ] Implement Mic + SD Audio mixdown for UAC1 Capture

### Phase 3: Application Logic (Layer 3)
- [ ] Scaffold `stinger_app.c` State Machine logic
- [ ] Implement Bank Switching logic via Encoder 1
  - [ ] Validate `/bankXX/` folder format and boundary wrapping (01–99)
- [ ] Implement Sub-Mixer gain scaling logic via Encoder 2
- [ ] Implement sample trigger/retrigger logic on Keypress (L1-L4, R1-R4)

### Phase 4: UI & Display Rendering
- [ ] Initialize `DisplayTask` (Core 0, Priority 2)
- [ ] Implement Boot Splash Screen logic (STINGER JP+)
  - [ ] Enforce 2-second timeout and SD-Card-absent fallback.
- [ ] Implement Main Layout Rendering
  - [ ] Zone 1: Bank Indicator logic
  - [ ] Zone 2: Button Labels (parsing `labels.cfg` or filename)
  - [ ] Zone 3: Status bar (Volume, Gain, Connection indicators)
- [ ] Implement dynamic display refresh on Bank Switch

### Phase 5: Concurrency & Transfer Mode
- [ ] Implement Transfer Mode Entry/Exit sequence (Shift + Enc2 Switch)
  - [ ] Drain DMA buffers and suspend `AudioMixerTask`
  - [ ] Release SD Mutex and unmount FAT32
  - [ ] Hand over SD control to USB MSC and update display to "TRANSFER MODE"
- [ ] Implement USB Disconnect state recovery logic
- [ ] Perform Audio stress testing (simultaneous sample overlaps)
- [ ] Final bug-fixing and memory-leak verification

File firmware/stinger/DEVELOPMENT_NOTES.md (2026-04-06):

# Stinger Firmware Development Notes

## Input System (Phase 1)
- **Matrix Scanning**: Initial implementation uses a 1ms scan interval with a 10us settling delay between row activation and column reading. If ghosting occurs with larger matrices or longer traces, consider increasing the settling delay or adding software debouncing logic beyond simple state change detection.
- **Encoder ISR**: Current implementation triggers on the falling edge of the A pin and reads the B pin state to determine direction. This is a lightweight approach. If resolution issues or "skipping" is observed during fast rotation, consider moving to a full 4-state quadrature state machine on both edges.
- **Layer 3 Routing**: All input events are funneled through a FreeRTOS queue (`s_app_queue`) to `stinger_app_task`. This decouples the low-level hardware timing from the application logic.

## Build System & Dependencies
- **USB Audio Component**: Temporarily disabled (`usb_audio/CMakeLists.txt.disabled`) due to missing `tinyusb` component dependency in the current environment. This needs to be resolved during Phase 2.
- **Pin Map**: `pin_map.h` is auto-generated. Manual edits will be overwritten. Always update `master_pins.json` (or `.yaml` as referenced in docs) and rebuild.
- **Component Requirements**: ESP-IDF v6.0 requires explicit component requirements in `idf_component_register`. For example, `esp_driver_gpio` must be explicitly listed in `REQUIRES`.

## Future Transitions
- **Transfer Mode**: Logic for Shift + Enc2 Switch hold is planned but not yet implemented. The scan task will provide the raw button events; the timing logic should reside in the Layer 3 state machine.
- **FreeRTOS Task Pinning**: Matrix scanning is pinned to Core 0 (Priority 20). Audio Mixer (Phase 2) should be pinned to Core 1 (Priority 25) to avoid starvation from UI/USB tasks.

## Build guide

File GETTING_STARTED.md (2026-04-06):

# Getting Started with Stinger Development

This guide will help you initialize your development environment, configure the IDE properly, and build the Stinger firmware for the ESP32-S3. Due to some quirks with ESP-IDF and the VS Code IDE, **please follow these steps carefully** to avoid CMake and IntelliSense errors.

## 📋 1. Prerequisites (macOS)

You'll need a few system tools. If you don't have Homebrew installed, get it from [brew.sh](https://brew.sh).

```bash
brew install cmake ninja dfu-util python3 git
```

## 🛠️ 2. ESP-IDF v6.0 Setup (via VS Code Extension)

The Stinger project requires **ESP-IDF v6.0**. It is highly recommended to manage this via the official VS Code Extension for automated tooling support.

1. **Install the Extension:** 
   Search for and install the official **Espressif IDF** extension in your VS Code extension manager.
2. **Run the Setup Wizard:** 
   Open the Command Palette (`Cmd+Shift+P`) and type `ESP-IDF: Configure ESP-IDF extension`.
3. **Install the Framework:**
   Choose **Express Setup**, select **v6.0** from the version dropdown, and allow the wizard to automatically download the framework and ESP32-S3 toolchains.

---

## ⚠️ 3. CRITICAL: IDE & Workspace Configuration

The most common cause of build failures (`Configure failed`, `include could not find requested file`) or false-positive code errors in this project stems from incorrect folder structures.

1. **Open the correct Workspace Folder:** 
   Do **NOT** open the root `Stinger` repository directory as your primary workspace folder in VS Code if you are doing firmware development. You **MUST** open the `firmware/stinger` directory as the root folder. 

2. **Verify Settings (`.vscode/settings.json`):**
   The project contains a pre-configured `.vscode/settings.json` located inside `firmware/stinger/`. It explicitly tells the IDE and CMake where the IDF tools are:
   - Sets `"cmake.environment": { "IDF_PATH": "..." }` so CMake doesn't fail on including the ESP-IDF boilerplate.
   - Sets Clangd arguments and disables conflicting IntelliSense parsing to prevent false `-mlongcalls` errors in IntelliSense.

3. **Verify C/C++ Properties (`.vscode/c_cpp_properties.json`):**
   This configures IntelliSense to use `compile_commands.json` generated by the build system.

*Note: If you change machines or ESP-IDF versions, you may need to update the absolute paths inside the `.vscode/settings.json` and `.vscode/c_cpp_properties.json` variables to match your local environment.*

---

## 🏗️ 4. Build & Flash Firmware

Using the extension toolbar at the bottom of VS Code:

1. **Set Target:** Click the device icon or run `ESP-IDF: Set Espressif device target` and select `esp32s3`.
2. **Build:** Click the ⚙️ (Build) icon or run `ESP-IDF: Build your project`.
3. **Flash & Monitor:** Click the ⚡️ (Flash) and 📺 (Monitor) icons to upload your code and view serial output.

*(You can also use the `ESP-IDF: Open ESP-IDF Terminal` command, where `idf.py build` will work automatically).*

---

## 🤖 5. Automated Pin Configuration

The Stinger project uses a single-source-of-truth for GPIO configurations.

**Do NOT manually edit `main/pin_map.h` or the layout tables in `SPEC.md`.**

If you need to change a pin assignment:
1. Edit `firmware/stinger/master_pins.json`.
2. Save your changes.
3. The build system automatically triggers `tools/generate_pins.py` which will regenerate `pin_map.h` and explicitly patch your changes into the `SPEC.md` root specification file.

---

## 📂 Project Structure

- `firmware/stinger/` — Main ESP-IDF project. **Open this directory in VS Code for firmware dev.**
  - `master_pins.json`: Hardware GPIO definitions (Single source of truth).
  - `main/board_config.h`: Master constants (Audio/USB/Display).
  - `tools/generate_pins.py`: Python code generation script.
- `hardware/` — KiCad design files (Brain and Plate boards).
- `SPEC.md` — Technical Specification.

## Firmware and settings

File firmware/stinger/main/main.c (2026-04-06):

#include <stdio.h>
#include "freertos/FreeRTOS.h"
#include "freertos/task.h"
#include "pin_map.h"
#include "board_config.h"
#include "stinger_app.h"

void app_main(void)
{
    printf("Stinger USB Audio Soundboard Initializing...\n");
    
    // Initialize Layer 3 application which coordinates all subsystems
    stinger_app_init();
    
    while(1) {
        vTaskDelay(pdMS_TO_TICKS(1000));
    }
}

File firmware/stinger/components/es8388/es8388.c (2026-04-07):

#include "es8388.h"
#include "driver/i2c_master.h"
#include "esp_log.h"
#include "esp_check.h"

// Note: These would ideally come from a board config component, 
// but we define them here to match the Stinger pin map for Phase 1.
#define I2C_MASTER_SCL_IO           5
#define I2C_MASTER_SDA_IO           4
#define I2C_MASTER_NUM              0
#define ES8388_I2C_ADDR             0x10

static const char *TAG = "ES8388";
static i2c_master_dev_handle_t s_dev_handle;

/**
 * @brief Write a single byte to an ES8388 register
 */
static esp_err_t es_write_reg(uint8_t reg_addr, uint8_t data) {
    uint8_t write_buf[2] = {reg_addr, data};
    return i2c_master_transmit(s_dev_handle, write_buf, sizeof(write_buf), -1);
}

/**
 * @brief Initialize the I2C master bus and device handle
 */
static esp_err_t i2c_master_init(void) {
    i2c_master_bus_config_t i2c_bus_config = {
        .clk_source = I2C_CLK_SRC_DEFAULT,
        .i2c_port = I2C_MASTER_NUM,
        .scl_io_num = I2C_MASTER_SCL_IO,
        .sda_io_num = I2C_MASTER_SDA_IO,
        .glitch_ignore_cnt = 7,
        .flags.enable_internal_pullup = true,
    };
    i2c_master_bus_handle_t bus_handle;
    ESP_RETURN_ON_ERROR(i2c_new_master_bus(&i2c_bus_config, &bus_handle), TAG, "I2C master bus init failed");

    i2c_device_config_t dev_cfg = {
        .dev_addr_length = I2C_ADDR_BIT_LEN_7,
        .device_address = ES8388_I2C_ADDR,
        .scl_speed_hz = 100000,
    };
    ESP_RETURN_ON_ERROR(i2c_master_bus_add_device(bus_handle, &dev_cfg, &s_dev_handle), TAG, "I2C device add failed");

    return ESP_OK;
}

esp_err_t es8388_init(void) {
    ESP_LOGI(TAG, "Initializing ES8388 Codec...");
    
    // 1. Initialize I2C Bus
    ESP_RETURN_ON_ERROR(i2c_master_init(), TAG, "I2C Init Failed");

    // 2. Hardware Resident Sequence (Based on ES8388 Datasheet/ESP-ADF)
    // -----------------------------------------------------------------
    // Reset and basic clocking
    ESP_RETURN_ON_ERROR(es_write_reg(ES8388_CONTROL1, 0x00), TAG, "Reg 0x00 failed");
    ESP_RETURN_ON_ERROR(es_write_reg(ES8388_CONTROL2, 0x00), TAG, "Reg 0x01 failed");
    
    // Chip Power management (DAC & ADC Power Up)
    ESP_RETURN_ON_ERROR(es_write_reg(ES8388_CHIPPOWER, 0x00), TAG, "Power up failed");
    
    // Master/Slave mode (Set to Slave, ESP32-S3 is Master)
    ESP_RETURN_ON_ERROR(es_write_reg(ES8388_MASTER_MODE, 0x00), TAG, "Master mode failed");
    
    // ADC/DAC Serial Interface Format (I2S, 16-bit)
    ESP_RETURN_ON_ERROR(es_write_reg(ES8388_ADC_CONTROL1, 0x00), TAG, "ADC Ctrl 1 failed");
    ESP_RETURN_ON_ERROR(es_write_reg(ES8388_DAC_CONTROL1, 0x00), TAG, "DAC Ctrl 1 failed");
    
    // Output Routing and Gain
    // Set DAC Output to LOUT1/ROUT1 (Headphones)
    ESP_RETURN_ON_ERROR(es_write_reg(ES8388_DAC_CONTROL17, 0x90), TAG, "DAC Ctrl 17 failed"); // Enable LOUT1/ROUT1
    ESP_RETURN_ON_ERROR(es_write_reg(ES8388_DAC_CONTROL20, 0x90), TAG, "DAC Ctrl 20 failed"); // Enable LOUT2/ROUT2 (Optional)
    
    // Unmute
    ESP_RETURN_ON_ERROR(es8388_set_voice_volume(70), TAG, "Initial volume set failed");

    ESP_LOGI(TAG, "ES8388 initialized successfully.");
    return ESP_OK;
}

esp_err_t es8388_set_voice_volume(int volume) {
    if (volume < 0) volume = 0;
    if (volume > 100) volume = 100;
    
    // Scale 0-100 to 0x00-0x21 (approx register range for ES8388 DAC volume)
    // In many implementations, 0x00 is max (0dB) and 0x21 is min (-96dB)
    // To keep it simple for now, we use the standard 0-33 range.
    uint8_t vol_reg = (uint8_t)((100 - volume) * 33 / 100);
    
    ESP_RETURN_ON_ERROR(es_write_reg(ES8388_DAC_CONTROL24, vol_reg), TAG, "Vol L failed");
    ESP_RETURN_ON_ERROR(es_write_reg(ES8388_DAC_CONTROL25, vol_reg), TAG, "Vol R failed");
    
    return ESP_OK;
}

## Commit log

2026-04-06 chore: restructure project directory for IDE, fix ESP-IDF workspace config and pin mappings
    [es8388.c, generate_pins.py]
2026-04-07 Hardware: Expand to 5x5 Matrix & Upgrade Interconnect to 14-pin IDC. Optimized GPIO 15 and updated BOM/Design Notes.
2026-04-07 Harden Git configuration: Update .gitignore for KiCad and IDE artifacts, reorganize hardware directories
    [brain.kicad_pcb, brain.kicad_sch, plate.kicad_pcb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]

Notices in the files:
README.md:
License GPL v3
